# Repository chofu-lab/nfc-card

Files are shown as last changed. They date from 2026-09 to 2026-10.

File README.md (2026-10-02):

# nfc-card — スマホをかざすと光る NFC 基板名刺

<p align="center">
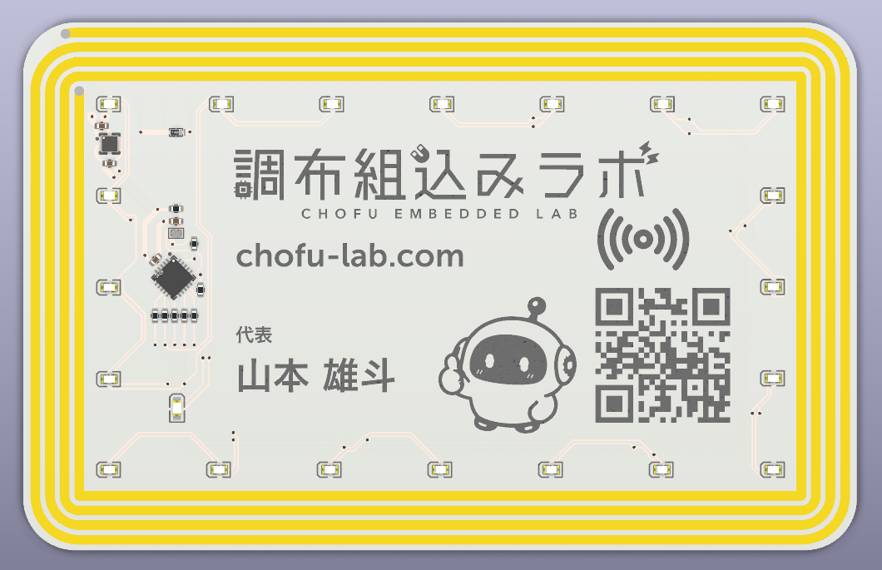
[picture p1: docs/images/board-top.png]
表面（KiCad の 3D ビュー）
  
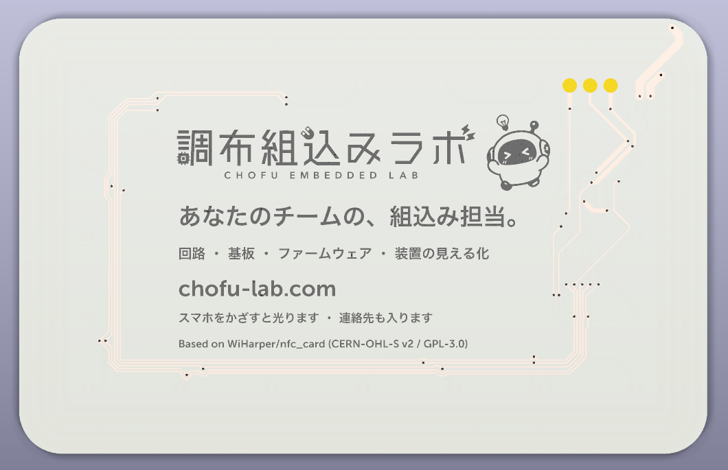
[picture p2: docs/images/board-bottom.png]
裏面（KiCad の 3D ビュー）
  
</p>

調布組込みラボの名刺用の基板です。電池はありません。スマホをかざすと、NFC の電波から取り出した電力でマイコンが起動し、外周の LED が光ります（Android の場合。iPhone はホーム画面での読み取りだと一瞬で終わるので、黄色の電源 LED が一瞬光ります）。

Wilson Harper さんの [WiHarper/nfc_card](https://github.com/WiHarper/nfc_card) をフォークし、シルク（ロゴ・文字・QR コード）を差し替え、JLCPCB で部品実装まで発注できるよう BOM を直したものです。回路・アンテナ・部品配置・配線は元の設計のままです。

*English summary is [below](#english).*

## 出典

- 元リポジトリ: [WiHarper/nfc_card](https://github.com/WiHarper/nfc_card)（commit `752793d`。このリポジトリはそのフォークで、元の履歴の上にこちらの変更を載せています。変更点は [`docs/CHANGES.md`](docs/CHANGES.md) にあります）
- 作者による解説: [wilsonharper.net/projects/businesscard](https://wilsonharper.net/projects/businesscard/)

回路・アンテナ・ファームウェアは元作者の設計です。公開してくださったことに感謝します。

## 状態

- 2026 年 9 月に JLCPCB へ 30 枚（部品実装込み）を発注し、届いた基板で確認しています
- 1 枚目で動作を確認済み（2026-10-01〜02）: Android は NFC をオンにしてかざしている間、LED が光り続けます（9 種類のパターンを 6 秒ずつ順番に）。iPhone 17 はホーム画面での読み取り（アプリなし）だと電波が約 0.1 秒で切れるので、黄色の電源 LED が一瞬光り、NFC に書いた URL の通知が出ます。iPhone でも、アプリで読み出しを続ければ（NFC Tools の高度なコマンドで READ を 2,500 回）約 14 秒光ります
- 共振周波数の実測は、確認できしだい追記します

## 構成（元の設計と同じ）

| 項目 | 内容 |
|---|---|
| NFC | NXP NT3H2111W0FHKH（NTAG I2C plus 1k）。受け取った電力の余りを VOUT 端子から出せる |
| マイコン | Microchip ATtiny816（QFN20、1 MHz 動作） |
| LED | 赤 20 個（GPIO 5 本でチャーリープレクス駆動）＋ 電源表示の黄 1 個 |
| 電源 | VOUT から 2.2kΩ（R3）を通して 10µF（C3）をゆっくり充電し、起動から約 300 ms 後にマイコンが P-ch MOSFET（Q1）をオンにして R3 をバイパスする |
| アンテナ | 基板パターンの矩形スパイラル 4 ターン（外寸 84×53 mm、線幅 1 mm・間隔 0.5 mm）。元の作者の設計値は約 2.75µH で、1.5pF（C1）で調整 |
| 基板 | 2 層、厚さ 0.8 mm、85.45×54.08 mm（クレジットカードとほぼ同じ大きさ） |
| 書き込み | 裏面の UPDI パッド 3 点（GND / VCC / UPDI） |

## 元の設計からの主な変更

- **シルクの差し替え**: 表にロゴ・URL・名前・QR コード・キャラクター、裏にキャッチコピーと出典表記。元の設計の NFC アイコンと、アンテナの銅箔を見せるレジスト抜きは残しています。電源 LED 横の稲妻マークは、差し替えのときに意図せず消してしまいました（発注した基板にも入っていません）
- **文字はフォントの輪郭で描画**: KiCad の標準フォント（一筆書き）ではなく、フォントの輪郭を多角形にして配置（`scripts/text2json.py`）
- **C1 の部品番号を修正**: 元の設計では 0402 サイズのフットプリントに 0603 サイズの LCSC 番号（C1639）が入っており、JLCPCB の実装審査で指摘されました。同じシリーズの 0402 品（C1552、1.5pF C0G）に変更
- **R4 に LCSC 番号を追加**（C25076。元の設計では空欄）。C1・R4 とも、回路図・基板ファイル・BOM のすべてで直しています
- **ファームウェアの光り方を変更**: 外周の赤 LED を、9 種類のパターン（元の彗星・双子の彗星・スピナー・すれ違い・交互点灯・満ちて引く・積み上げ・きらめき・チャージ）を 6 秒ずつ順番に流す形にした。元のファームウェアの小さな遊びだったモールス信号はやめた。起動時の演出（0.3 秒待ってから 0.3 秒かけて明るくなる）は元のまま
- **電源 LED（黄）を起動直後に点灯**: iPhone のホーム画面での読み取り（アプリなし）は電波が約 0.1 秒で切れるため（iPhone 17 で確認）、元の設計（0.3 秒待ってから 0.3 秒かけて点灯）では何も光らなかった。黄色だけマイコンの起動後すぐに点けて、iPhone でも一瞬光るようにした。そのあとは、パターンが切り替わるたびに光って 0.5 秒で消える
- **描画の周期を 6 ms に固定し、待つ間はマイコンをスリープ**: LED 1 個あたりの明るさと電流は元の設計と同じ。全部の LED が点く場面では赤の合計電流が増えるが、スリープと黄色の消灯で、基板全体の平均電流は元の設計より少ない見込み（シミュレーションによる推定）
- **JLCPCB 用の製造データを追加**（`hardware/fab/`）
- **基板ファイルを KiCad 10 で保存**（`.kicad_pcb` は KiCad 9 では開けません。回路図は KiCad 9 形式のまま）

詳細は [`docs/CHANGES.md`](docs/CHANGES.md) にあります。

## ファイル構成

| パス | 内容 |
|---|---|
| `hardware/` | KiCad のプロジェクト（回路図・基板・部品ライブラリ）。基板は KiCad 10 形式 |
| `hardware/fab/` | 製造データ（ガーバー、JLCPCB 用 BOM・部品配置） |
| `software/` | ファームウェア `nfc_card.ino`（光り方のパターンと電源 LED の動きを変更）、ビルドに使うライブラリ（megaTinyCore・AVR-LibC）のライセンス表示 `THIRD_PARTY_NOTICES.md`（megaTinyCore のライセンス全文は `LICENSE-megaTinyCore.md`）、アンテナを描く KiCad 用スクリプト `coil.py`（元の設計のまま） |
| `scripts/` | シルクを差し替えるスクリプト |
| `artwork/` | シルクの素材（ロゴ・キャラクター・文字の輪郭データ） |

## 製造（JLCPCB）

`hardware/fab/` の次の 3 つをアップロードします。

- `nfc-card-gerbers.zip`（ガーバー）
- `bom_jlcpcb.csv`（BOM）
- `positions_jlcpcb.csv`（部品配置）

KiCad が出力した BOM・部品配置ファイルは、そのままでは JLCPCB に読み込めなかったため、JLCPCB の書式に合わせたものを用意しています。

発注したときの設定:

- 2 層、厚さ 0.8 mm、30 枚
- 白レジスト・黒シルク、表面処理 ENIG
- 高精度シルク（High-precision Printing）。裏面の小さい文字が標準シルクの下限より細いため
- 部品実装: 標準（Standard PCBA）、表面のみ、捨て基板の除去あり

## 書き込み

ATtiny816 には裏面のパッドから UPDI で書き込みます（クロックは 1 MHz）。ビルドの方法は [`software/THIRD_PARTY_NOTICES.md`](software/THIRD_PARTY_NOTICES.md) にあります。何枚も続けて書くときは、[`software/flash_cards.sh`](software/flash_cards.sh)（macOS、SerialUPDI のアダプタを使用）で「基板をクリップではさむ → Enter」をくり返せます。NFC チップの電源の上限は 3.6V なので、アダプタの電源は 3.3V にしてください（5V にしない）。

NFC チップ（NTAG I2C plus）は出荷時に初期化されていない（CC が 0）ため、iPhone からは書き込めず、Android の NXP TagWriter でもうまく書けないことがありました。Android の「NTAG I2C Demoboard」アプリ（NXP）の Config →「Reset tag」で初期化してから、URL や vCard を書きます。初期化のあとは iPhone の NFC TagWriter でも書けます。元の作者によると、エネルギーハーベストは初期状態で有効です。

## シルクを作り直すとき

スクリプトは macOS 前提です（KiCad とフォントのパスが書き込んであります）。

1. 素材をシルク用の多角形データにする（Pillow と potrace が必要）。文言や画像を変えるときだけ必要で、生成済みのデータは `artwork/` に入っています
   - 文字: `python3 scripts/text2json.py`。フォントの既定はヒラギノ角ゴシック W6（macOS 同梱）と Museo Sans 700（別途インストールが必要）で、`--jp` / `--en` で差し替えられます
   - 画像: `python3 scripts/art2json.py ...`（オプションはスクリプト冒頭のコメント参照）
2. 元の設計の基板ファイルを取得し、KiCad 同梱の Python で `artwork.py` → `hide_refs.py` の順に実行する。リポジトリ内の基板ファイルは上書きされます

```bash
cd hardware
curl -L -o "Business Card v2.kicad_pcb" "https://raw.githubusercontent.com/WiHarper/nfc_card/752793dcc3164dadf245cb0bc9e7e368e9c0e78e/hardware/Business%20Card%20v2.kicad_pcb"
PY=/Applications/KiCad/KiCad.app/Contents/Frameworks/Python.framework/Versions/Current/bin/python3
$PY ../scripts/artwork.py
$PY ../scripts/hide_refs.py
```

`hide_refs.py` を別プロセスで実行するのは、KiCad 10.0.3 の Python API が、図形を大量に追加したあと同じプロセスで操作を続けると落ちることがあるためです。

作り直した基板ファイルでは、C1・R4 の LCSC 欄が元の設計の値に戻ります。KiCad の「回路図から基板を更新」で合わせるか、BOM は `hardware/fab/bom_jlcpcb.csv` を使ってください。ガーバーは KiCad の製造ファイル出力で作り、JLCPCB 用の CSV は `hardware/fab/` の既存ファイルと同じ列にそろえます。

## ライセンス

元の設計と同じライセンスです。この基板の設計データ一式の置き場所（CERN-OHL-S の Source Location）は、このリポジトリ https://github.com/chofu-lab/nfc-card です。

- `hardware/`・`artwork/`・`docs/`: [CERN-OHL-S v2](https://ohwr.org/cern_ohl_s_v2.txt)
- `software/`・`scripts/`: [GPL-3.0-or-later](https://www.gnu.org/licenses/gpl-3.0.html)

基板に書き込むファームウェアには、megaTinyCore（LGPL 2.1）と AVR-LibC（修正 BSD ライセンス）の一部が含まれます。著作権表示とライセンスの全文は [`software/THIRD_PARTY_NOTICES.md`](software/THIRD_PARTY_NOTICES.md) にあります。配った基板のファームウェアのソースコード（ビルドに使った megaTinyCore のソースを含む）は、基板をお渡ししてから少なくとも 3 年間、このリポジトリから無料で入手できるようにしておきます。

「調布組込みラボ」の名称・ロゴ・キャラクター「ちょふまる」は、標章としての利用を許諾していません。この設計をもとに名刺を作る場合は、ご自身のデザインに差し替えてください。詳しくは [`LICENSE.md`](LICENSE.md) を参照してください。

---

## English

A business-card PCB for Chofu Embedded Lab (Tokyo, Japan). It has no battery: when you hold a phone near it, the NFC chip harvests energy from the field, wakes up an ATtiny816, and the LEDs around the edge light up (on Android; when an iPhone reads it from the home screen, the read ends almost at once, so only the yellow power LED blinks).

This is a fork of [WiHarper/nfc_card](https://github.com/WiHarper/nfc_card) by Wilson Harper. The circuit, antenna, placement, and routing are unchanged. What changed:

- New silkscreen artwork (logo, name, QR code, character), drawn from real font outlines instead of KiCad stroke fonts
- C1 LCSC part number fixed: the original BOM had C1639 (0603) on a 0402 footprint; replaced with C1552 (0402, 1.5 pF C0G)
- Added the missing LCSC number for R4 (C25076)
- The lightning mark next to the power LED was unintentionally removed during the silkscreen replacement (it is also missing on the boards we ordered)
- Firmware: the red LEDs now play nine patterns for 6 s each (the original comet, twin comets, spinner, crossing, alternating, fill, stack, twinkle, and charge). The Morse code easter egg is gone. The start-up animation (0.3 s wait and 0.3 s fade-in) is unchanged
- Firmware: the yellow power LED now turns on as soon as the MCU starts. A background NFC read from the iPhone home screen (no app) keeps the field on for only about 0.1 s (checked on an iPhone 17), so with the original 0.3 s delay plus 0.3 s fade-in nothing lit up on an iPhone. After that it flashes and fades out over 0.5 s at each pattern change
- Firmware: each frame is fixed at 6 ms with the CPU sleeping in between, so one LED is as bright and draws as much current as in the original firmware. The total red current grows when many LEDs are lit, but the estimated average current of the whole board is lower than the original (simulation)
- JLCPCB-ready fabrication files in `hardware/fab/`
- The board file is saved with KiCad 10 (it will not open in KiCad 9). The schematic is still in KiCad 9 format

Status: 30 boards were ordered from JLCPCB in September 2026 and have been delivered. Checked on the first board (2026-10-01 to 02): on Android the LEDs keep playing the patterns while the phone is held near the card; on an iPhone 17 a home-screen read shows the URL notification and only the yellow LED blinks. With an app that keeps reading the tag (2,500 READ commands in NFC Tools), the card stays lit for about 14 s. Antenna resonance measurements will be added later.

Source location of this design: https://github.com/chofu-lab/nfc-card

License: same as the original, CERN-OHL-S v2 for `hardware/`, `artwork/`, and `docs/`, and GPL-3.0-or-later for `software/` and `scripts/`. The firmware includes parts of megaTinyCore (LGPL 2.1) and AVR-LibC (modified BSD); see [`software/THIRD_PARTY_NOTICES.md`](software/THIRD_PARTY_NOTICES.md). The source of the firmware on the boards we hand out (including the megaTinyCore source used to build it) stays available here free of charge for at least three years after we hand out a board. The Chofu Embedded Lab name, logo, and character are not licensed for use as marks. Please replace them with your own artwork. See [`LICENSE.md`](LICENSE.md).

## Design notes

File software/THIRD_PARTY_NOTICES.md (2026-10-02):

# サードパーティのライセンス表示（Third-party notices）

名刺のマイコン（ATtiny816）に書き込むファームウェア `nfc_card.ino` は、Arduino 環境で次のライブラリと一緒にビルドしています。ファームウェアを書き込んだ基板を人に渡すため、それぞれのライセンスが求める表示をここにまとめます。

The firmware `nfc_card.ino` is built with the libraries below. These notices accompany the boards we hand out.

## 配った基板のファームウェア（Distributed firmware）

- タグ `firmware-2` の `software/nfc_card.ino` をビルドしたもの（`firmware-1` は配る前に差し替えた版です。ファームウェアを変えたときは、新しいタグを打ってここに追記します）
- Built from `software/nfc_card.ino` at tag `firmware-2` (`firmware-1` was replaced before any boards were handed out; a new tag will be added here whenever the firmware changes).

## ビルドの方法（Build）

- ボード定義: megaTinyCore 2.6.11（Arduino のボードマネージャ。追加の URL は `http://drazzy.com/package_drazzy.com_index.json`）
- コンパイラ: avr-gcc 7.3.0-atmel3.6.1-azduino7b1（megaTinyCore を入れると、依存するツールとして一緒に入ります。AVR-LibC 2.0.0 を含みます）
- FQBN: `megaTinyCore:megaavr:atxy6:chip=816,clock=1internal`
- 書き込み: SerialUPDI（230400 baud、write delay あり）

Arduino のスケッチは「フォルダ名」と「.ino のファイル名」が同じである必要があるので、`nfc_card` という名前のフォルダに `nfc_card.ino` を置いてからビルドします。リポジトリのトップで実行します（`nfc_card/` と `build/` は作業用のフォルダです）。

```
arduino-cli core install megaTinyCore:megaavr@2.6.11 --additional-urls http://drazzy.com/package_drazzy.com_index.json
mkdir nfc_card && cp software/nfc_card.ino nfc_card/
arduino-cli compile -b megaTinyCore:megaavr:atxy6:chip=816,clock=1internal --output-dir build nfc_card
arduino-cli upload -b megaTinyCore:megaavr:atxy6:chip=816,clock=1internal -P serialupdi230k_wd1 -p <シリアルポート> --input-dir build nfc_card
```

## megaTinyCore — GNU LGPL 2.1

ファームウェアには、megaTinyCore 2.6.11 の次のファイルから作られた部分が静的にリンクされています。

- `cores/megatinycore/` の main.cpp・wiring.c・wiring_micros_ISR.h・wiring_digital.c・wiring_analog.c・Arduino.h
- `variants/txy6/pins_arduino.h`

著作権表示（各ファイルの見出しより）:

```
Copyright (c) 2005-2013 Arduino
Copyright (c) 2005-2006, 2007 David A. Mellis
Copyright (c) 2018-2022, 2025 Spence Konde
```

- ライセンスの全文: このフォルダの [`LICENSE-megaTinyCore.md`](LICENSE-megaTinyCore.md)（megaTinyCore 2.6.11 の LICENSE.md の写し。GNU LGPL 2.1 の全文を含みます）
- ソースコード: https://github.com/SpenceKonde/megaTinyCore （タグ 2.6.11）。ビルドに使ったソース一式は、このリポジトリの Release `firmware-2`（と `firmware-1`）にも `megaTinyCore-2.6.11.tar.bz2`（SHA-256: `1a2b5827777aa4c61ac5d9e96cf4ad9ebb34a2171a97288349df8eb61636cfb1`）として添付しています

このフォルダの `nfc_card.ino`（GPL-3.0-or-later）と megaTinyCore のソースがあれば、上の方法で同じファームウェアをビルドでき、megaTinyCore を変更してから再リンクすることもできます。

The firmware is statically linked with parts of megaTinyCore 2.6.11, licensed under the GNU LGPL 2.1 (full text in `LICENSE-megaTinyCore.md`). Together with `nfc_card.ino` in this folder and the megaTinyCore source (also attached to the releases `firmware-2` and `firmware-1`), you can rebuild and relink the firmware.

## AVR-LibC 2.0.0 — Modified BSD License

ファームウェアには AVR-LibC 2.0.0（avr-gcc と一緒に入る C ライブラリとスタートアップコード）の一部が含まれます。条件に従い、著作権表示とライセンス条文を以下に掲載します（AVR-LibC 2.0.0 の `LICENSE` より。https://github.com/avrdudes/avr-libc/blob/avr-libc-2_0_0-release/LICENSE ）。

```
The contents of avr-libc are licensed with a Modified BSD License.

All of this is supposed to be Free Software, Open Source, DFSG-free,
GPL-compatible, and OK to use in both free and proprietary applications.

See the license information in the individual source files for details.

Additions and corrections to this file are welcome.

*******************************************************************************
Portions of avr-libc are Copyright (c) 1999-2010
Keith Gudger,
Bjoern Haase,
Steinar Haugen,
Peter Jansen,
Reinhard Jessich,
Magnus Johansson,
Artur Lipowski,
Marek Michalkiewicz,
Colin O'Flynn,
Bob Paddock,
Reiner Patommel,
Michael Rickman,
Theodore A. Roth,
Juergen Schilling,
Philip Soeberg,
Anatoly Sokolov,
Nils Kristian Strom,
Michael Stumpf,
Stefan Swanepoel,
Eric B. Weddington,
Joerg Wunsch,
Dmitry Xmelkov,
The Regents of the University of California.
All rights reserved.

   Redistribution and use in source and binary forms, with or without
   modification, are permitted provided that the following conditions are met:

   * Redistributions of source code must retain the above copyright
     notice, this list of conditions and the following disclaimer.

   * Redistributions in binary form must reproduce the above copyright
     notice, this list of conditions and the following disclaimer in
     the documentation and/or other materials provided with the
     distribution.

   * Neither the name of the copyright holders nor the names of
     contributors may be used to endorse or promote products derived
     from this software without specific prior written permission.

   THIS SOFTWARE IS PROVIDED BY THE COPYRIGHT HOLDERS AND CONTRIBUTORS "AS IS"
   AND ANY EXPRESS OR IMPLIED WARRANTIES, INCLUDING, BUT NOT LIMITED TO, THE
   IMPLIED WARRANTIES OF MERCHANTABILITY AND FITNESS FOR A PARTICULAR PURPOSE
   ARE DISCLAIMED. IN NO EVENT SHALL THE COPYRIGHT OWNER OR CONTRIBUTORS BE
   LIABLE FOR ANY DIRECT, INDIRECT, INCIDENTAL, SPECIAL, EXEMPLARY, OR
   CONSEQUENTIAL DAMAGES (INCLUDING, BUT NOT LIMITED TO, PROCUREMENT OF
   SUBSTITUTE GOODS OR SERVICES; LOSS OF USE, DATA, OR PROFITS; OR BUSINESS
   INTERRUPTION) HOWEVER CAUSED AND ON ANY THEORY OF LIABILITY, WHETHER IN
   CONTRACT, STRICT LIABILITY, OR TORT (INCLUDING NEGLIGENCE OR OTHERWISE)
   ARISING IN ANY WAY OUT OF THE USE OF THIS SOFTWARE, EVEN IF ADVISED OF THE
   POSSIBILITY OF SUCH DAMAGE.
```

## GCC のランタイムライブラリ（libgcc）

libgcc は GCC Runtime Library Exception の対象で、ビルドしたファームウェアに表示の義務はありません。

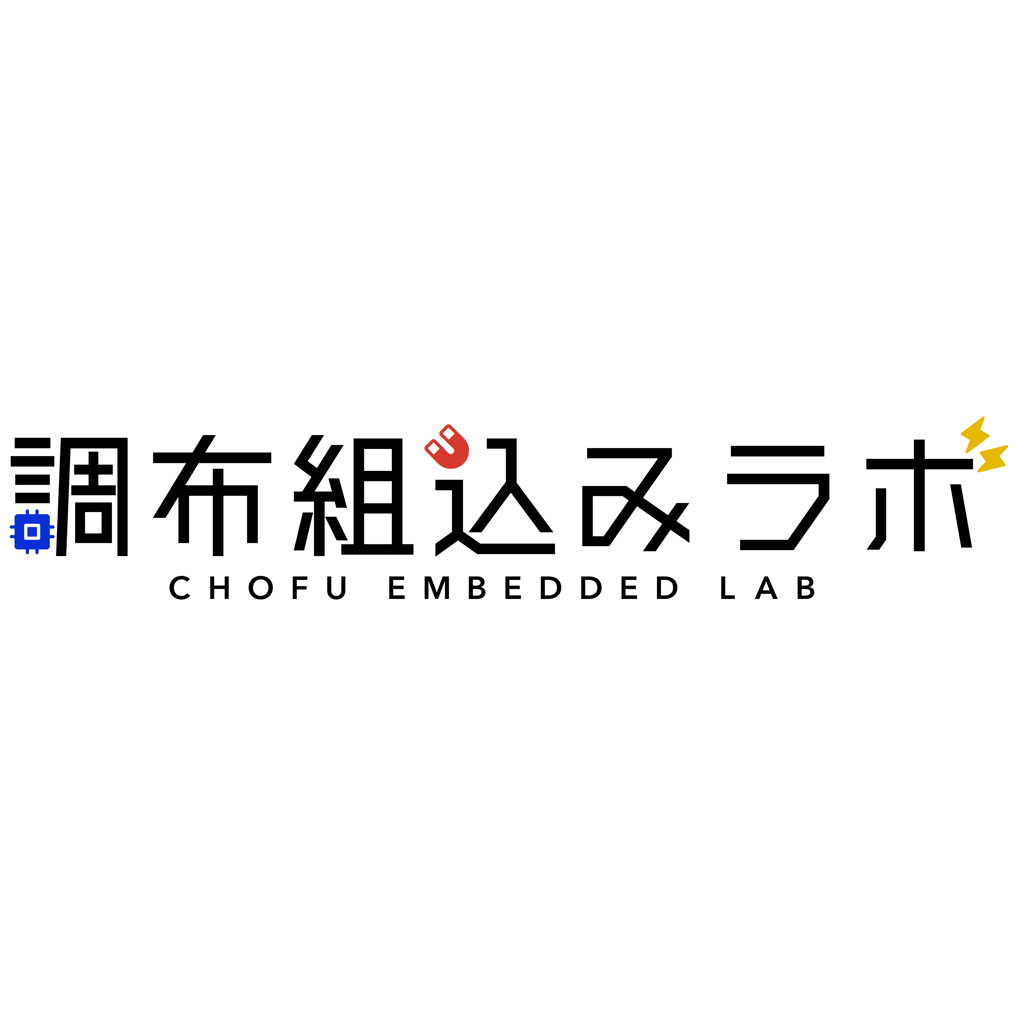
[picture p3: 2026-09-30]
artwork/wordmark-h-en-4000.png

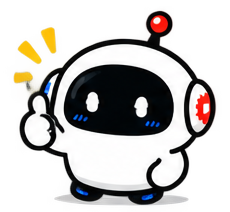
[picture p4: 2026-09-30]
artwork/pose-thumbs-up.png

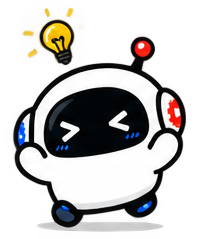
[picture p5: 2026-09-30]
artwork/pose-idea.png

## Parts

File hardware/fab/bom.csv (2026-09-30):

Comment | Designator | Footprint | LCSC Part # | Qty
1.5p | C1 | Capacitor_SMD:C_0402_1005Metric | C1552 | 1
100n | C2,C4 | Capacitor_SMD:C_0402_1005Metric | C1525 | 2
10u | C3 | Capacitor_SMD:C_0402_1005Metric | C15525 | 1
TPESD8LS5_0CT5G | D1 | JLCImport:TPESD8L3_3CT5G | C2827551 | 1
XL-1608SURC-06FJ | LED1-LED20 | JLCImport:XL-1608SURC-06FJ | C7371900 | 20
XL-1608UYC-06FJ | LED22 | JLCImport:XL-1608UYC-06FJ | C7371901 | 1
DMP21D0UFB4-P | Q1 | JLCImport:DMP21D0UFB4-P | C2905648 | 1
100 | R1,R4-R7 | Resistor_SMD:R_0402_1005Metric | C25076 | 5
100k | R2 | Resistor_SMD:R_0402_1005Metric | C25741 | 1
2.2k | R3 | Resistor_SMD:R_0402_1005Metric | C25879 | 1
220 | R8 | Resistor_SMD:R_0402_1005Metric | C25091 | 1
ATTINY816-MNR | U1 | JLCImport:ATTINY816-MNR | C2052778 | 1
NT3H2111W0FHKH | U3 | JLCImport:NT3H2111W0FHKH | C710403 | 1

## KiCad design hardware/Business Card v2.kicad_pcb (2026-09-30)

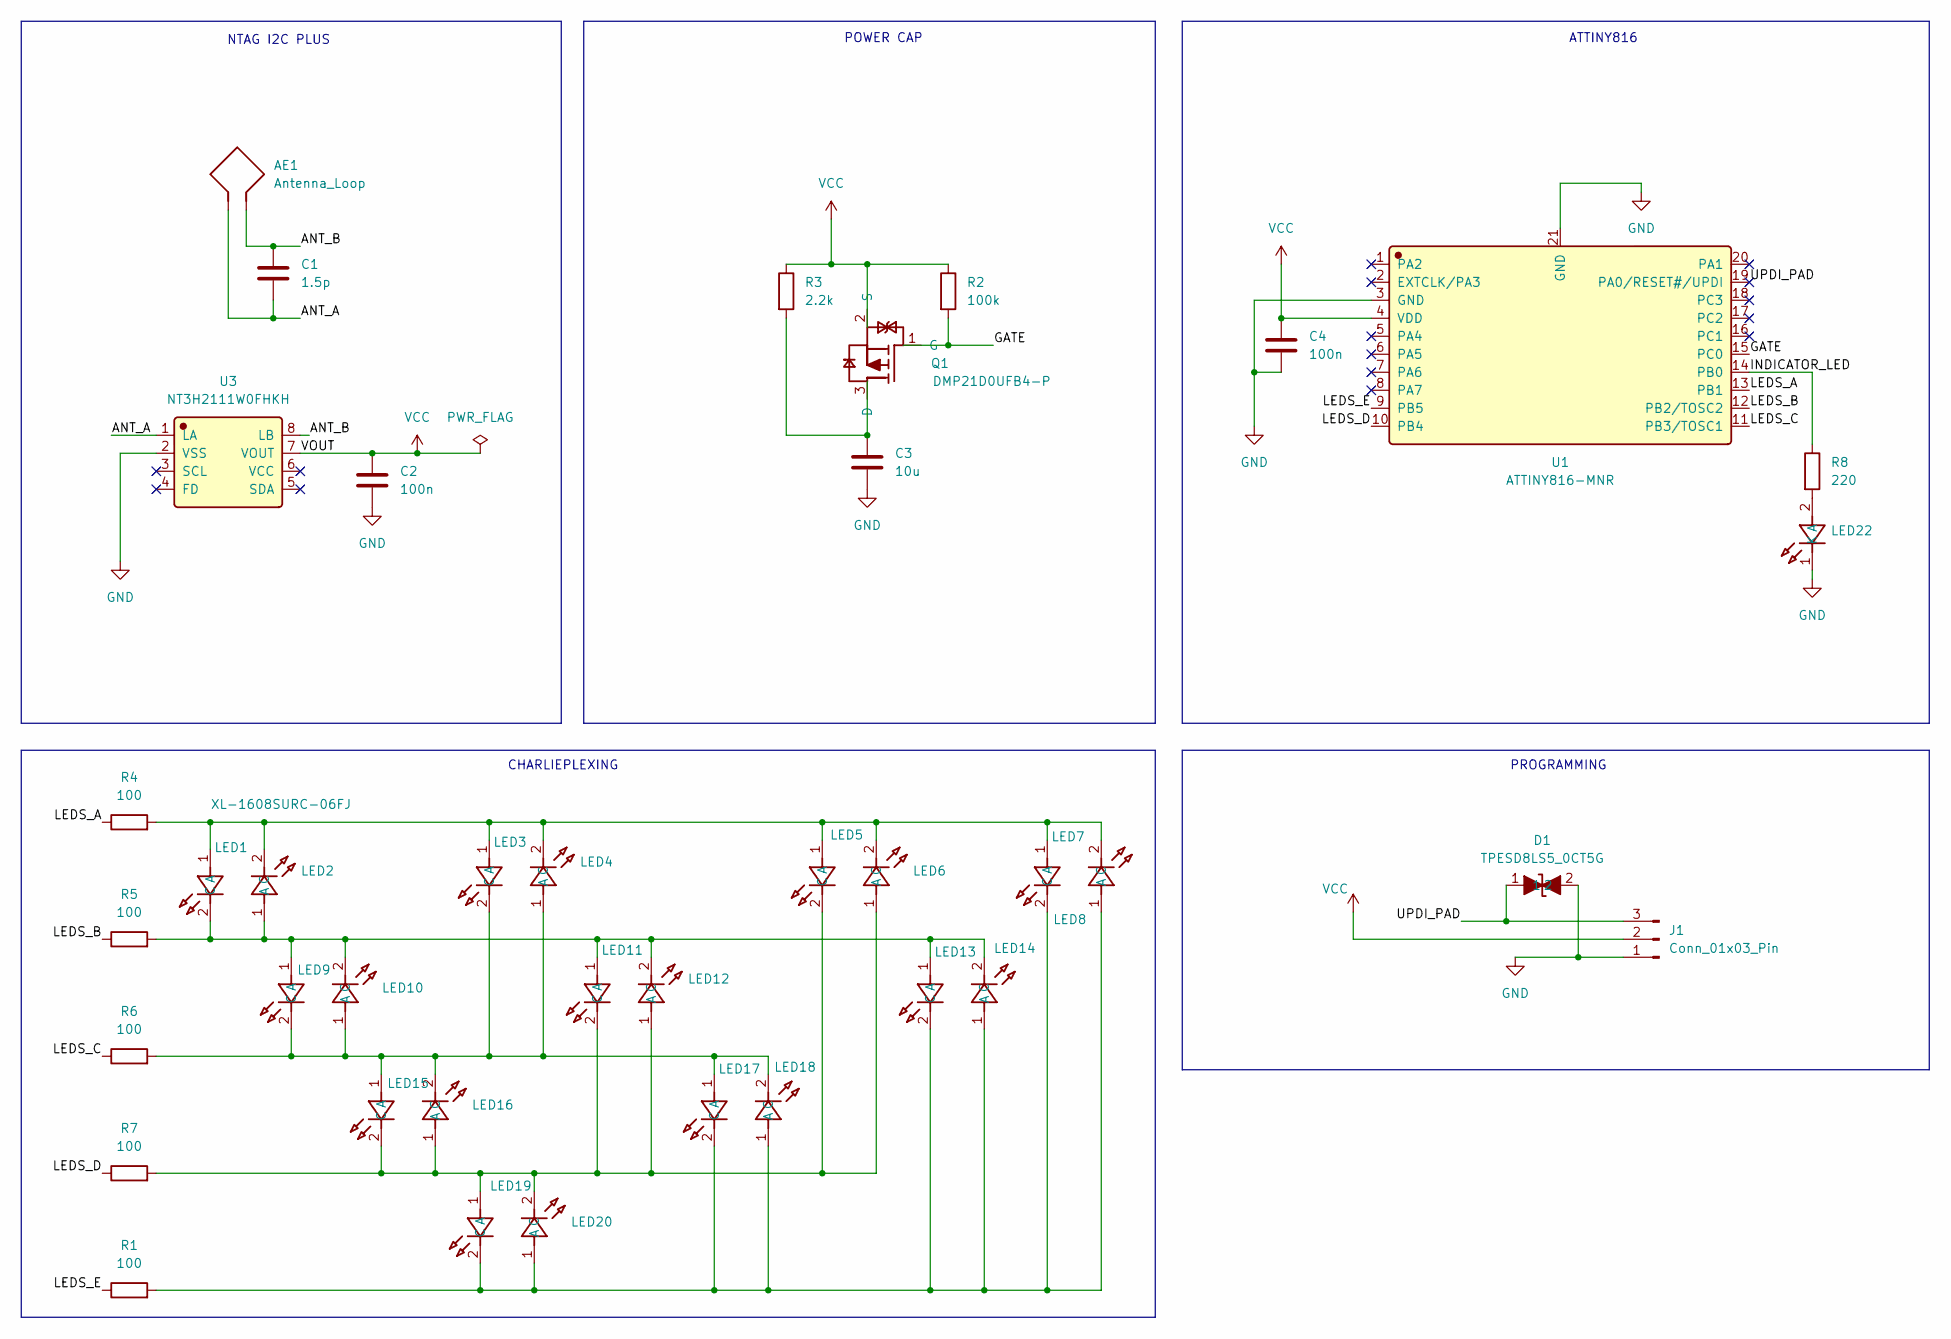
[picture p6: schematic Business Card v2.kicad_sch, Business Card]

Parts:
AE1: Antenna_Loop; Antenna V3
C1: 1.5p; C_0402_1005Metric; LCSC C1552
C2, C4: 100n; C_0402_1005Metric; LCSC C1525
C3: 10u; C_0402_1005Metric; LCSC C15525
D1: TPESD8LS5_0CT5G; TPESD8L3_3CT5G; Manufacturer Part TPESD8LS5.0CT5G; LCSC C2827551
J1: Conn_01x03_Pin; Offset UPDI
LED1, LED2, LED3, LED4, LED5, LED6, LED7, LED8, LED9, LED10, LED11, LED12, LED13, LED14, LED15, LED16, LED17, LED18, LED19, LED20: XL-1608SURC-06FJ; Manufacturer Part XL-1608SURC-06FJ; LCSC C7371900
LED22: XL-1608UYC-06FJ; Manufacturer Part XL-1608UYC-06FJ; LCSC C7371901
Q1: DMP21D0UFB4-P; Manufacturer Part DMP21D0UFB4-P; LCSC C2905648
R1, R4, R5, R6, R7: 100; R_0402_1005Metric; LCSC C25076
R2: 100k; R_0402_1005Metric; LCSC C25741
R3: 2.2k; R_0402_1005Metric; LCSC C25879
R8: 220; R_0402_1005Metric; LCSC C25091
U1: ATTINY816-MNR; Manufacturer Part ATTINY816-MNR; LCSC C2052778
U3: NT3H2111W0FHKH; Manufacturer Part NT3H2111W0FHKH; LCSC C710403

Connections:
/ANT_A: AE1.1, C1.2, U3.1 (LA)
/ANT_B: AE1.2, C1.1, U3.8 (LB)
/GATE: Q1.1 (G), R2.2, U1.15 (PC0)
/INDICATOR_LED: R8.1, U1.14 (PB0)
/LEDS_A: R4.1, U1.13 (PB1)
/LEDS_B: R5.1, U1.12 (PB2/TOSC2)
/LEDS_C: R6.1, U1.11 (PB3/TOSC1)
/LEDS_D: R7.1, U1.10 (PB4)
/LEDS_E: R1.1, U1.9 (PB5)
/UPDI_PAD: D1.1, J1.3, U1.19 (PA0/RESET#/UPDI)
GND: C2.2, C3.2, C4.2, D1.2, J1.1, LED22.1 (K), U1.3 (GND), U1.21 (GND), U3.2 (VSS)
unnamed: LED1.1 (A), LED2.2 (C), LED3.1 (A), LED4.2 (C), LED5.1 (A), LED6.2 (C), LED7.2 (C), LED8.1 (A), R4.2
unnamed: LED1.2 (C), LED2.1 (A), LED9.1 (A), LED10.2 (C), LED11.1 (A), LED12.2 (C), LED13.1 (A), LED14.2 (C), R5.2
unnamed: LED3.2 (C), LED4.1 (A), LED9.2 (C), LED10.1 (A), LED15.1 (A), LED16.2 (C), LED17.1 (A), LED18.2 (C), R6.2
unnamed: LED5.2 (C), LED6.1 (A), LED11.2 (C), LED12.1 (A), LED15.2 (C), LED16.1 (A), LED19.1 (A), LED20.2 (C), R7.2
unnamed: LED7.1 (A), LED8.2 (C), LED13.2 (C), LED14.1 (A), LED17.2 (C), LED18.1 (A), LED19.2 (C), LED20.1 (A), R1.2
unnamed: LED22.2 (A), R8.2
unnamed: C3.1, Q1.3 (D), R3.2
VCC: C2.1, C4.1, J1.2, Q1.2 (S), R2.1, R3.1, U1.4 (VDD), U3.7 (VOUT)

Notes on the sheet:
NTAG I2C PLUS
POWER CAP
ATTINY816
PROGRAMMING
CHARLIEPLEXING

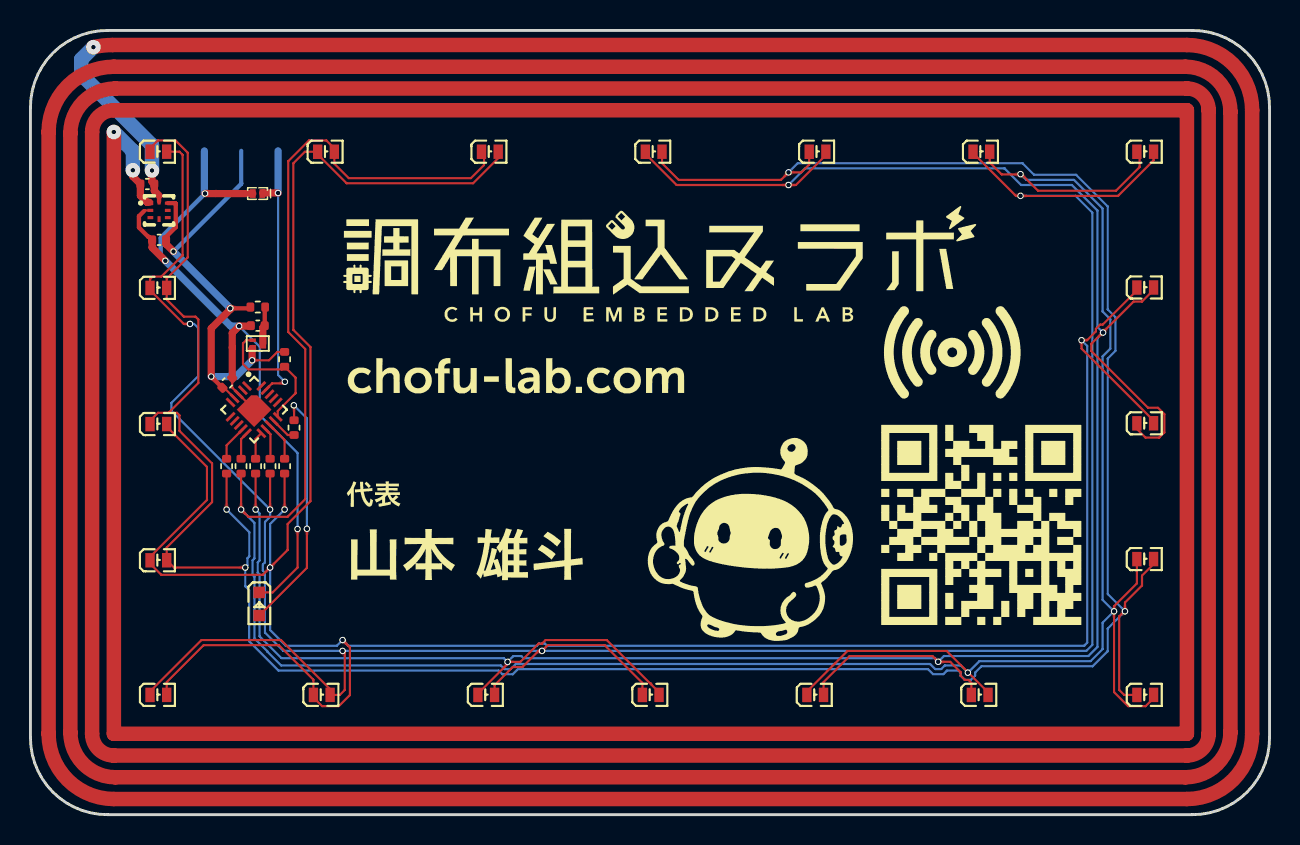
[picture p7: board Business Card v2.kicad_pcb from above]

Board: 2 copper layers, 85.4 x 54.1 mm, 39 parts (1 on the bottom side), 19 nets.

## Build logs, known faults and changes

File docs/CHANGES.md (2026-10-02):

# 元の設計（WiHarper/nfc_card @752793d）からの変更履歴

CERN-OHL-S v2 の 3.3(b) に基づき、元の設計からの変更点を記録します。

## 2026-09-16

- 元リポジトリ（752793d）から `hardware/`・`software/`・`LICENSE.md` を引き継ぎ。`gallery/`（元の作者の名刺の写真・動画）と KiCad の一時ファイル（`*.kicad_sch-bak`・`*.kicad_prl`）は削除し、README は置き換え
- 基板ファイル（`.kicad_pcb`）を KiCad 10.0.3 で保存し、KiCad 10 形式になった（KiCad 9 では開けない）。回路図（`.kicad_sch`）は KiCad 9 形式のまま
- 外形・アンテナ・部品配置・配線は変更なし
- 表裏のシルクとレジストの図形を差し替え（`scripts/artwork.py`、素材は `artwork/`）
  - 削除: 元の作者の氏名・連絡先・QR コード・ブロック図・"Made by" 表記（基板上の図形。フットプリント内の図形は残す）
  - 残したもの: アンテナの銅箔を見せる F.Mask の抜き、NFC アイコン（QR コードの上へ移動）
  - 意図せず消えたもの: 電源 LED（LED22）横の稲妻マーク。`artwork.py` で残す範囲の判定（中心 x < 123 mm）に対し、図形の中心が x ≒ 123.05 mm で、範囲から外れていた。発注した基板にも入っていない
  - 表に追加: ロゴ、chofu-lab.com、肩書と氏名、キャラクター（ちょふまる）、QR コード（https://chofu-lab.com/）
  - 裏に追加: ロゴ、キャラクター、キャッチコピー、URL、「スマホをかざすと光ります」、出典表記 "Based on WiHarper/nfc_card (CERN-OHL-S v2 / GPL-3.0)"
  - 部品の参照記号（D1、U1 など）はシルクに出さない（`scripts/hide_refs.py`）
- 基板色を白レジスト・黒シルク前提に。QR コードは暗いセルをシルクで塗る（`artwork.py` の `DARK_BOARD = False`）。OpenCV で読み取れることを確認
- 回路図: R4 に LCSC 番号 C25076 を追加（元の設計では空欄で、BOM に抜けが出ていた）
- 製造データ `hardware/fab/` を追加（ガーバー、BOM、部品配置）
  - アンテナ AE1 と UPDI パッド J1 は実装部品ではないので BOM・部品配置から除外（13 品目 37 点）
  - KiCad の CSV は JLCPCB で読み込めなかったため、JLCPCB の書式に合わせた `bom_jlcpcb.csv`・`positions_jlcpcb.csv` を追加

## 2026-09-18

- シルクの文字を、KiCad のストロークフォントからフォントの輪郭（多角形）に変更（`scripts/text2json.py`、`artwork.py` の `place_text()`）
  - 日本語: ヒラギノ角ゴシック W6、英語: Museo Sans 700
  - 最も細い線は約 0.12 mm で、標準シルクの下限（0.15 mm）を下回るため、高精度シルク（下限 0.1 mm）で発注する
- キャラクターとロゴの輪郭を、拡大 → ぼかし → 二値化 → potrace の手順で滑らかに再抽出（`scripts/art2json.py`）
- 検証: 銅箔・レジスト・外形・ドリルのガーバーは変更前と一致。DRC は既知の誤検出 4 件のみ（アンテナ図形とそのパッドの重なり。元の設計でも同じ）

## 2026-09-21

- C1 の LCSC 番号を C1639 から C1552 に変更
  - 元の設計の回路図では、C1 のフットプリントが `C_0402_1005Metric`（0402）なのに、LCSC 番号は C1639（FH 0603CG1R5C500NT、0603）になっていた。JLCPCB の実装審査で「部品がパッドより大きい」と指摘された
  - C1552（FH 0402CG1R5C500NT、1.5pF ±0.25pF、C0G、50V、0402）は同じメーカー・同じシリーズのサイズ違いで、電気的な仕様は同じ
  - 回路図の LCSC 欄と `hardware/fab/bom.csv`・`bom_jlcpcb.csv` を更新。ガーバー・部品配置は変更なし
- BOM の残り 12 品目は、LCSC のパッケージ情報とフットプリントを照合して一致を確認

## 2026-09-30

- 公開に向けて整理
  - `hardware/bom/ibom.html`（元の設計のシルクのまま）と、古い製造データの zip を削除
  - 使っていない素材（`artwork/mark-chip.svg`・`mark.json`・`wordmark-h-en-makinas.svg`）を削除
  - 基板ファイル内の部品情報を回路図に合わせた（C1 の LCSC 欄を C1639 → C1552、R4 に LCSC 欄 C25076 を追加。非表示のフィールドだけで、ガーバーは全層変わらないことを確認）
  - `artwork/`・`docs/`・`scripts/` のライセンス、この設計の置き場所（Source Location）、ロゴ・キャラクターの扱いを `LICENSE.md` に追記
  - README の画像（`docs/images/`、KiCad の 3D ビュー）を追加

## 2026-10-01

- ファームウェア（`software/nfc_card.ino`）: 電源 LED（LED22）が起動の 10 秒後から点滅させるモールス信号の文字列を、元の作者のサイト名 "WILSONHARPER.NET" から "CHOFU-LAB.COM" に変更。変えたのは `morseSequence` の配列だけで、符号の長さ・間隔の決め方（短点 1・長点 3・符号間 1・文字間 3・最後に 7 単位、1 単位 170 ms）は元のまま
- ファームウェア: 電源 LED（黄、LED22）を、電源が入った直後に点けるように変更。元の設計では起動から 0.3 秒待ってから 0.3 秒かけてフェードインしていたため、読み取りが約 0.1 秒で終わる iPhone（待ち受け中の読み取り）では何も光らなかった。赤の LED（外周 20 個）の起動の演出（0.3 秒待ってからフェードイン）と、突入電流対策の待ち時間（0.3 秒後に Q1 をオン）は元のまま。ただし、その 0.3 秒間（C3 を R3 経由で充電している間）も黄色の LED（R8 220Ω）に電流が流れるようになった（元の設計では、この間 LED は消えていた）
- ファームウェア: ビルドに使う megaTinyCore（LGPL 2.1）と AVR-LibC 2.0.0（修正 BSD）のライセンス表示を `software/THIRD_PARTY_NOTICES.md` に、megaTinyCore 2.6.11 の LICENSE.md の写しを `software/LICENSE-megaTinyCore.md` に追加

## 2026-10-02（ファームウェア firmware-2）

- 光り方: 外周の赤 LED を、9 種類のパターンを 6 秒ずつ順番に流す形にした（元の彗星 2 周 → 双子の彗星 → スピナー〔4 つの点〕→ すれ違い → 交互点灯 → 満ちて引く → 積み上げ → きらめき → チャージ）。彗星は 1 歩 150 ms（元の設計は 67 フレームごとに 1 歩で、実際には約 0.4 秒）。パターンは 25 ms ごとに更新する
- 電源 LED（黄）: 起動直後の点灯（2026-10-01 の変更）はそのまま。そのあとはふだん消灯し、パターンが切り替わるたびに光って 0.5 秒でフェードアウトする。チャージの最後の点滅では赤と一緒に点灯する。モールス信号と起動後 10 秒の呼吸はやめた（2026-10-01 のモールス信号の文字列の変更も、これで取りやめ）
- 描画の周期: 元の設計は LED ごとの割り算（`% 20`）に時間がかかり、1 フレームが約 6 ms だった。割り算をなくすと点灯時間の割合が約 3 倍になり電流が増えるため、TCB0 の周期割り込みで 1 フレームを 6 ms に固定し、待つ間は IDLE スリープにした。LED 1 個あたりの明るさと電流は元と同じ。赤の合計電流は点いている数に比例するので、平均は元の約 1.2 倍、20 個全部が点く瞬間は約 3 倍になる。スリープと黄の消灯で、基板全体の平均電流は元より少ない見込み（サイクル単位のシミュレーションによる推定で約 0.69 mA → 約 0.52 mA）
- 起動: 0.3 秒待ってから MOSFET（Q1）をオンにする突入電流対策と、赤の 0.3 秒のフェードインは元のまま。フェードの最後で、まれに約 65 ms 消灯する問題（元の設計から。`millis()` を 2 回読むため）を直した

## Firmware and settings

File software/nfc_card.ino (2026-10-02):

#include <avr/sleep.h>


const int powerBypassPin = PIN_PC0;
const int powerLedPin = PIN_PB0;


struct LedMap {
  uint8_t anodeIdx;
  uint8_t cathodeIdx;
};


const LedMap leds[20] = {
  {1, 4}, {4, 1}, {0, 4}, {4, 0}, {0, 1}, {1, 0}, {1, 2}, {2, 1},
  {2, 3}, {3, 2}, {3, 4}, {4, 3}, {0, 2}, {2, 0}, {1, 3}, {3, 1},
  {2, 4}, {4, 2}, {0, 3}, {3, 0}
};


struct LedMasks {
  uint8_t dir_mask;
  uint8_t out_mask;
};
LedMasks ledMasks[20];


// Each frame starts every FRAME_US, the same frame period as the original firmware.
// One LED at a given level has the same brightness and average current as before.
// Total red current still grows with the number of lit LEDs. The CPU sleeps until the next frame.
#define FRAME_US 6000
static_assert(FRAME_US >= 1000 && FRAME_US <= 65536, "FRAME_US must fit TCB0 (1 count = 1 us at 1 MHz)");
static_assert(F_CPU == 1000000UL, "the frame timer and the on-time table assume 1 MHz");
volatile bool frameDue = false;


// LED patterns, played in this order and repeated
#define TICK_MS 25          // the patterns are updated every tick
#define COMET_TICKS 6       // a comet moves by one LED every 6 ticks (150 ms)
#define BLINK_TICKS 12      // the alternating pattern swaps every 12 ticks (300 ms)
#define CHARGE_TICKS 240    // the ring charges up slowly and blinks twice with the power LED (6 s)
#define CHARGE_RAMP_TICKS 208   // charging part (5.2 s), the rest is the two blinks
#define TWINKLE_TICKS 17    // one twinkle fades in and out over this many ticks
#define FLASH_MS 500        // the power LED flashes and fades out over this time at each pattern change
static_assert(FLASH_MS >= 128 && FLASH_MS <= 65535, "FLASH_MS must be 128..65535");
constexpr uint16_t flashFadeK = 127UL * 65536UL / FLASH_MS;


enum Pattern : uint8_t { COMET, TWIN_COMETS, SPINNER, CROSSING, ALTERNATE, FILL, STACK, TWINKLE, CHARGE };


struct Segment {
  Pattern pattern;
  uint16_t ticks;           // length in TICK_MS (240 ticks = 6 s)
};


const Segment playlist[] = {
  {COMET, 240},             // 2 laps
  {TWIN_COMETS, 240},       // 2 laps
  {SPINNER, 240},           // four dots, 2 laps
  {CROSSING, 240},          // the two dots meet four times
  {ALTERNATE, 240},         // 20 blinks
  {FILL, 240},              // fill the ring one by one, then empty it in the same order
  {STACK, 240},             // a dot runs and piles up at the end (210 ticks), then the ring blinks
  {TWINKLE, 240},           // random LEDs fade in and out
  {CHARGE, 240},            // charges up once
};
const uint8_t playlistLength = sizeof(playlist) / sizeof(playlist[0]);


// brightness of each LED as an index into the on-time table (0 = brightest, 16 = dimmest), LED_OFF = dark
#define LED_OFF 0xFF
uint8_t ledLevel[20];


uint8_t segmentIndex = 0;
uint16_t segmentTick = 0;
uint8_t cometTick = 0;
uint16_t frameCounter = 0;
unsigned long tickStartTime = 0;
unsigned long segmentStartTime = 0;
uint8_t powerLevel = 0xFF;
uint8_t patternPowerLevel = 0;   // the power LED level a pattern asks for (CHARGE)


uint8_t twinkleWait[20];    // ticks until the next twinkle of each LED
uint8_t twinklePos[20];     // position in the current twinkle, 0 = not twinkling
uint16_t rngState = 0xACE1;


void setup() {
  // light the power LED right away: a background read from the iPhone home screen (no app)
  // keeps the NFC field on for only about 0.1 s, so in that case this is the only LED that lights up
  pinMode(powerLedPin, OUTPUT);
  analogWrite(powerLedPin, 127);


  // in-rush prevention
  delay(300);


  // enable bypass MOSFET
  pinMode(powerBypassPin, OUTPUT);
  digitalWrite(powerBypassPin, LOW);



  // pre-calculate hardware bitmasks
  for (int i = 0; i < 20; i++) {
    uint8_t aMask = (1 << (leds[i].anodeIdx + 1));
    uint8_t cMask = (1 << (leds[i].cathodeIdx + 1));
    ledMasks[i].dir_mask = aMask | cMask;
    ledMasks[i].out_mask = aMask;
  }


  PORTB.DIRCLR = 0x3E;


  // frame timer: TCB0 periodic interrupt, 1 count = 1 us at 1 MHz
  TCB0.CCMP = FRAME_US - 1;
  TCB0.CTRLB = TCB_CNTMODE_INT_gc;
  TCB0.INTCTRL = TCB_CAPT_bm;
  TCB0.CTRLA = TCB_CLKSEL_CLKDIV1_gc | TCB_ENABLE_bm;
  set_sleep_mode(SLEEP_MODE_IDLE);


  startSegment();
  uint32_t startupStart = millis();


  while (true) {
    uint32_t elapsed = millis() - startupStart;
    if (elapsed >= 300) break;
    waitFrame();
    // The counter has just restarted, so it is below the new limit.
    TCB0.CCMP = FRAME_US - 1 + (uint16_t)(300 - elapsed) * 25;   // a longer frame is dimmer: 13.5 ms -> 6 ms
    renderFrame(0);
  }
  // Only one render (~1.3 ms) has elapsed, so restoring the 6 ms limit is safe.
  TCB0.CCMP = FRAME_US - 1;


  // the power LED fades out like a pattern change flash
  tickStartTime = millis();
  segmentStartTime = tickStartTime;
}


void loop() {
  waitFrame();
  unsigned long now = millis();


  if (now - tickStartTime >= TICK_MS) {
    tickStartTime += TICK_MS;
    if (++cometTick >= COMET_TICKS) cometTick = 0;


    if (++segmentTick >= playlist[segmentIndex].ticks) {
      if (++segmentIndex >= playlistLength) {
        segmentIndex = 0;
      }
      segmentStartTime = now;
      startSegment();
    } else {
      updateLevels();
    }


    if (cometTick == 0) {
      frameCounter = 0;
    }
  }


  // time since the comet moved, for fading out the end of its tail
  uint16_t msInStep = cometTick * TICK_MS + (uint16_t)(now - tickStartTime);
  renderFrame(msInStep);
  frameCounter++;


  updatePowerLed(now);
}


ISR(TCB0_INT_vect) {
  TCB0.INTFLAGS = TCB_CAPT_bm;
  frameDue = true;
}


// sleep (IDLE) until the next frame starts. Interrupts are re-enabled right before sleep_cpu(),
// so a frame interrupt cannot slip in between the check and going to sleep
void waitFrame() {
  cli();
  while (!frameDue) {
    sleep_enable();
    sei();
    sleep_cpu();
    sleep_disable();
    cli();
  }
  frameDue = false;
  sei();
}


void startSegment() {
  segmentTick = 0;
  cometTick = 0;


  for (uint8_t i = 0; i < 20; i++) {
    twinkleWait[i] = random8() % 40;
    twinklePos[i] = 0;
  }


  updateLevels();
}


// recalculate ledLevel[] once per tick
void updateLevels() {
  Pattern pattern = playlist[segmentIndex].pattern;
  uint8_t step = segmentTick / COMET_TICKS;
  uint8_t head = step % 20;


  // STACK: find how many LEDs have piled up and where the running dot is
  uint8_t stacked = 0;
  uint8_t dot = LED_OFF;
  bool stackLit = false;
  if (pattern == STACK) {
    uint16_t t = segmentTick;
    while (stacked < 20 && t >= (uint8_t)(20 - stacked)) {
      t -= 20 - stacked;
      stacked++;
    }
    if (stacked < 20) {
      dot = t;
    } else {
      stackLit = t < 24 && (t / 6) % 2 == 0;   // blink twice when full, then go dark
    }
  }


  // CHARGE: the whole ring brightens (the on-time table is roughly exponential, so stepping
  // the level linearly looks like a smooth fade), then blinks twice together with the power LED
  uint8_t chargeLevel = LED_OFF;
  patternPowerLevel = 0;
  if (pattern == CHARGE) {
    uint8_t c = segmentTick % CHARGE_TICKS;
    if (c < CHARGE_RAMP_TICKS) {
      if (c >= 4) chargeLevel = 16 - (c - 4) * 16 / (CHARGE_RAMP_TICKS - 5);
    } else if ((c - CHARGE_RAMP_TICKS) / 8 % 2 == 0) {
      chargeLevel = 0;
      patternPowerLevel = 127;
    }
  }


  uint8_t blinkPhase = (segmentTick / BLINK_TICKS) & 1;


  // no divisions inside this loop: it runs every tick at 1 MHz
  for (uint8_t i = 0; i < 20; i++) {
    uint8_t d1 = head >= i ? head - i : head + 20 - i;   // behind the head that moves to higher indexes
    uint8_t level = LED_OFF;


    switch (pattern) {
      case COMET:
        if (d1 < 17) level = d1;
        break;


      case TWIN_COMETS: {
        uint8_t d2 = d1 >= 10 ? d1 - 10 : d1 + 10;           // second head on the opposite side
        uint8_t d = d1 < d2 ? d1 : d2;
        if (d < 8) level = d;
        break;
      }


      case SPINNER: {
        uint8_t d = d1;                    // behind the nearest of four heads 5 LEDs apart
        while (d >= 5) d -= 5;
        if (d < 4) level = d * 3;
        break;
      }


      case CROSSING: {
        uint8_t d2 = i + head >= 20 ? i + head - 20 : i + head;   // behind a head that moves to lower indexes
        uint8_t d = d1 < d2 ? d1 : d2;
        if (d < 6) level = d;
        break;
      }


      case ALTERNATE:
        if ((i & 1) == blinkPhase) level = 0;
        break;


      case FILL:
        if (step < 20 ? i <= step : i > step - 20) level = 0;
        break;


      case STACK:
        if (stacked < 20 ? (i >= 20 - stacked || i == dot) : stackLit) level = 0;
        break;


      case TWINKLE:
        if (twinklePos[i] > 0) {
          uint8_t p = twinklePos[i] - 1;   // 0 .. TWINKLE_TICKS - 1: dim -> bright -> dim
          level = (p < 8 ? 8 - p : p - 8) * 2;
          if (++twinklePos[i] > TWINKLE_TICKS) {
            twinklePos[i] = 0;
            twinkleWait[i] = 15 + random8() % 50;
          }
        } else if (twinkleWait[i] > 0) {
          twinkleWait[i]--;
        } else {
          twinklePos[i] = 1;
        }
        break;


      case CHARGE:
        level = chargeLevel;
        break;
    }


    ledLevel[i] = level;
  }
}


void renderFrame(uint16_t msInStep) {
  bool fadeTailEnd = playlist[segmentIndex].pattern == COMET;


  for (uint8_t i = 0; i < 20; i++) {
    uint8_t level = ledLevel[i];


    if (level == LED_OFF) {
      continue;
    }


    // the end of the long comet tail fades out over the step
    if (level == 16 && fadeTailEnd) {
      if (msInStep >= COMET_TICKS * TICK_MS * 50 / 67) continue;
      else if (msInStep >= COMET_TICKS * TICK_MS * 34 / 67 && (frameCounter & 3) != 0) continue;
      else if (msInStep >= COMET_TICKS * TICK_MS * 17 / 67 && (frameCounter & 1) != 0) continue;
    }


    uint8_t dm = ledMasks[i].dir_mask;
    uint8_t om = ledMasks[i].out_mask;


    PORTB.OUTCLR = dm;
    PORTB.OUTSET = om;
    PORTB.DIRSET = dm;


    switch (level) {
      case 0:
      case 1:
      case 2:  __builtin_avr_delay_cycles(100); break;
      case 3:  __builtin_avr_delay_cycles(70);  break;
      case 4:  __builtin_avr_delay_cycles(48);  break;
      case 5:  __builtin_avr_delay_cycles(32);  break;
      case 6:  __builtin_avr_delay_cycles(22);  break;
      case 7:  __builtin_avr_delay_cycles(15);  break;
      case 8:  __builtin_avr_delay_cycles(10);  break;
      case 9:  __builtin_avr_delay_cycles(7);   break;
      case 10: __builtin_avr_delay_cycles(5);   break;
      case 11: __builtin_avr_delay_cycles(4);   break;
      case 12: __builtin_avr_delay_cycles(3);   break;
      case 13: __builtin_avr_delay_cycles(2);   break;
      case 14: __builtin_avr_delay_cycles(1);   break;
      case 15: __builtin_avr_delay_cycles(1);   break;
      case 16: __builtin_avr_delay_cycles(1);   break;
    }


    PORTB.DIRCLR = dm;
  }
}


// flash the power LED at each pattern change and let it fade out
void updatePowerLed(unsigned long now) {
  unsigned long since = now - segmentStartTime;
  uint8_t level = 0;


  if (since < FLASH_MS) {
    uint16_t r = 127 - (((uint32_t)(uint16_t)since * flashFadeK) >> 16);
    level = (r * r) >> 7;   // fades softly
  }
  if (patternPowerLevel > level) {
    level = patternPowerLevel;
  }


  if (level != powerLevel) {
    analogWrite(powerLedPin, level);
    powerLevel = level;
  }
}


// 16-bit Galois LFSR for the twinkles
uint8_t random8() {
  uint8_t lsb = rngState & 1;
  rngState >>= 1;
  if (lsb) rngState ^= 0xB400;
  return rngState;
}

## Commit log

2026-09-30 調布組込みラボ版 NFC 基板名刺
    WiHarper/nfc_card（752793d）のフォーク。シルクを調布組込みラボ版に差し替え、
    JLCPCB で部品実装まで発注できるよう BOM を修正した（C1 の LCSC 番号の
    サイズ違いを修正、R4 に LCSC 番号を追加、JLCPCB 用の製造データを追加）。
    回路・アンテナ・部品配置・配線は元の設計のまま。変更点は docs/CHANGES.md に記録。
    [Business Card v2-B_Cu.gbr, Business Card v2-B_Mask.gbr, Business Card v2-B_Silkscreen.gbr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]
2026-10-01 ファームのモールス信号を CHOFU-LAB.COM に変更
    電源 LED が起動 10 秒後から点滅させる文字列を、元の作者のサイト名
    WILSONHARPER.NET から CHOFU-LAB.COM に変えた。morseSequence の配列のみ変更し、
    符号の長さ・間隔の規則（1 単位 170 ms）は元のまま。
2026-10-01 電源 LED を起動直後に点灯し、ファームのライセンス表示を追加
    - ファーム: 黄色の電源 LED をマイコンの起動直後に点ける。iPhone のホーム画面での
    読み取りは電波が約 0.1 秒で切れるため、元の 0.3 秒待ち＋0.3 秒フェードインでは
    何も光らなかった。赤の LED の演出と突入電流対策のタイミングは元のまま
    - software/THIRD_PARTY_NOTICES.md: ビルドに使う megaTinyCore（LGPL 2.1）と
    AVR-LibC 2.0.0（修正 BSD）の著作権表示・条文、ビルド手順、配った基板の版（タグ firmware-1）
    - software/LICENSE-megaTinyCore.md: megaTinyCore 2.6.11 の LICENSE.md の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
    [nfc_card.ino]
2026-10-02 ファームウェア firmware-2: 9 種類の光り方と、6 ms 固定の描画・スリープ
    - 外周の赤 LED: 元の彗星・双子の彗星・スピナー・すれ違い・交互点灯・満ちて引く・
    積み上げ・きらめき・チャージの 9 パターンを 6 秒ずつ順番に流す（25 ms ごとに更新、
    彗星は 1 歩 150 ms）
    - 電源 LED（黄）: 起動直後の点灯は維持し、パターンの切り替えで光って 0.5 秒で消える。
    モールス信号と起動後の呼吸はやめた
    - 描画: TCB0 の周期割り込みで 1 フレームを 6 ms に固定し、待つ間は IDLE スリープ。
    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

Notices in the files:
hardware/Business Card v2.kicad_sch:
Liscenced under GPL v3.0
